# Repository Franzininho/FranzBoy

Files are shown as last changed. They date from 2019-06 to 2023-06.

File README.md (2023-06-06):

View this project on [CADLAB.io](https://cadlab.io/project/27016). 

# FranzBoy by Franzininho

FranzBoy é uma placa no formato de game. Possui display OLED, 6 teclas e é baseado no microcontolador Atmega328.

## Pinagem

OLED:
- PC4: SDA - A4
- PC5: SCL - A5
 
BOTÕES:
- UP:	PD3 - D3
- DOWN: PD4 - D4
- LEFT: PD2 - D2
- RIGHT: PD5 - D5
- A: PD6 - D6
- B: PD7 - D7

USB:
- D+: PD2 - D2
- D-: PD4 - D4

BUZZER: PB1 - D9

IR: PB2 - D10
 
LED: PB5 - D13

## upload do código usando bootloader do Arduino UNO e conversor USB/Serial

Como ainda não temos um bootloader específico para a Franzboy, vamos usar o bootloader do Arduino Uno emprestado.

Na IDE do Arduino, configure para a programação da placa Arduino UNO:
- Ferramentas-> placa: Arduino Uno

Selecione também a porta USB atribuida ao conversor USB serial.

Faça a seguinte ligação:

|  FranzBoy | Conversor USB/Serial  |
| --- | --- |
|  DTR | DTR  |
|  RX | RX  |
|  TX | TX  |
|  VCC | VCC  |
|  CTS |  CTS |
|  GND |  GND |

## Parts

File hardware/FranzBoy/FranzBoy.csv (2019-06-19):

Id | Designator | Package | Quantity | Designation | Supplier and ref
1 | U3 | TP4056_BREAKOUT | 1 | TP4056_BREAKOUT
2 | G***,G*** | invaders | 2 | LOGO
3 | REF**,REF**,REF**,REF** | MountingHole_3.2mm_M3 | 4 | MountingHole_3.2mm_M3
4 | BZ1 | Buzzer_12x9.5RM7.6 | 1 | Buzzer
5 | U1 | DIP-28_W7.62mm_Socket_LongPads | 1 | ATmega328-PU
6 | SW1,SW2,SW3,SW4,SW5,SW6 | SW_PUSH_6mm_h4.3mm | 6 | SW_Push
7 | ISP | Pin_Header_Straight_2x03_Pitch2.54mm | 1 | AVR-ISP-6
8 | R1 | R_0603_HandSoldering | 1 | 10k
9 | C1,C4 | C_0603_HandSoldering | 2 | 100nF
10 | J2 | Pin_Header_Straight_1x06_Pitch2.54mm | 1 | Conn_01x06_Male
11 | C2,C3 | C_0603_HandSoldering | 2 | 22pF
12 | Y1 | Crystal_SMD_HC49-SD_HandSoldering | 1 | 16 MHz
13 | Q1,Q2 | SOT-23_Handsoldering | 2 | MMBT3904
14 | LCD1 | Oled96 | 1 | Oled96
15 | R2,R3 | R_0603_HandSoldering | 2 | 4k7
16 | C5,C6 | C_0603_HandSoldering | 2 | 10uF
17 | D1 | LED_0603_HandSoldering | 1 | LED
18 | R4,R9,R10,R11 | R_0603_HandSoldering | 4 | 1k
19 | D2,D3 | D_MiniMELF_Handsoldering | 2 | D_Zener
20 | R5 | R_0603_HandSoldering | 1 | 1k5
21 | R6 | R_0603_HandSoldering | 1 | 1M
22 | R7,R8 | R_0603_HandSoldering | 2 | 68R
23 | D4 | D_MiniMELF_Handsoldering | 1 | 1N4148
24 | J3 | Pin_Header_Straight_1x02_Pitch2.54mm | 1 | Conn_01x02_Male
25 | U2 | SOT-223-3_TabPin2 | 1 | LM1117-3.3
26 | BT1 | CR2032_HOLDER | 1 | Battery_Cell
27 | SW7 | SW_HH_SS12D07-G4-2 | 1 | SW_SPDT
28 | REF** | MountingHole_15x3mm | 1 | MountingHole_3mm_oval
29 | D5 | LED_D5.0mm_Horizontal_O1.27mm_Z3.0mm | 1 | LD271
30 | J5 | Pin_Header_Straight_1x04_Pitch2.54mm | 1 | Conn_01x04_Male
31 | J6 | Pin_Header_Straight_1x07_Pitch2.54mm | 1 | Conn_01x07_Male
32 | JP1 | SolderJumper-2_P1.3mm_Open_TrianglePad1.0x1.5mm | 1 | SolderJumper_2_Open
33 | J4 | USB_Micro-B-LCSC-C10418-and-C40946-C319167 | 1 | USB_B_Micro
34 | G*** | logo-franzininho12_7 | 1 | LOGO
35 | G*** | bandeiraBrasil | 1 | LOGO
36 | REF*** | KiCad-Logo2_6mm_SilkScreen | 1 | KiCad-Logo2_6mm_SilkScreen
37 | G*** | invaders2 | 1 | LOGO

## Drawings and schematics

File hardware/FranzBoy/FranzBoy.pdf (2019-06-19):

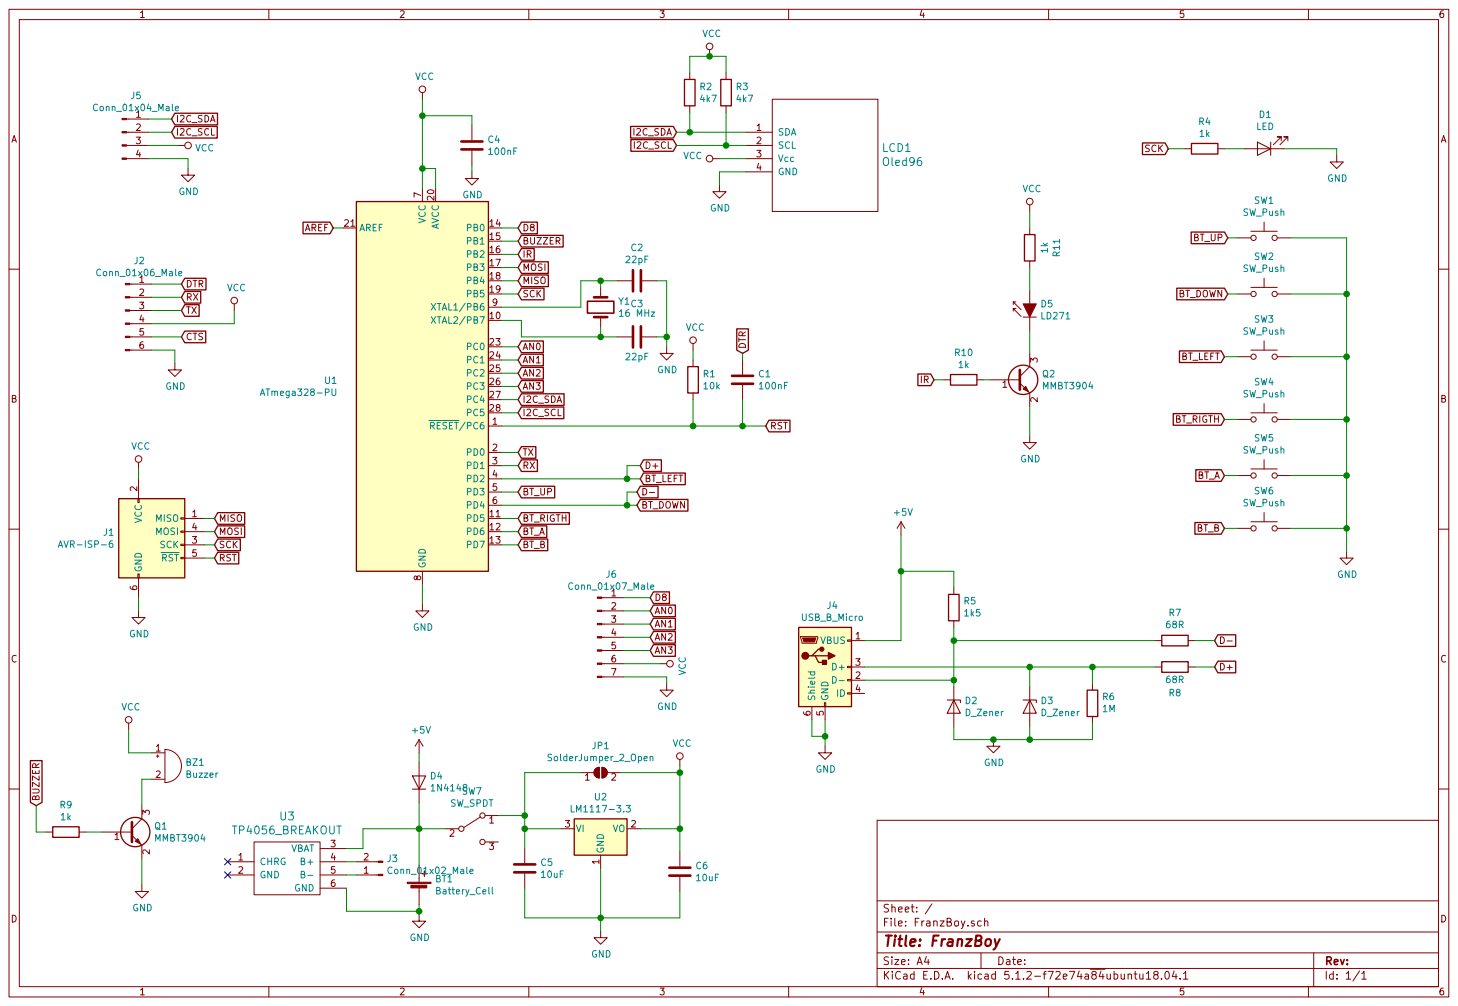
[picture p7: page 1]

2 SCK 3 MOSI 4 RST 5 GND

File: FranzBoy.sch Sheet: /
Id: 1/1 Title: FranzBoy

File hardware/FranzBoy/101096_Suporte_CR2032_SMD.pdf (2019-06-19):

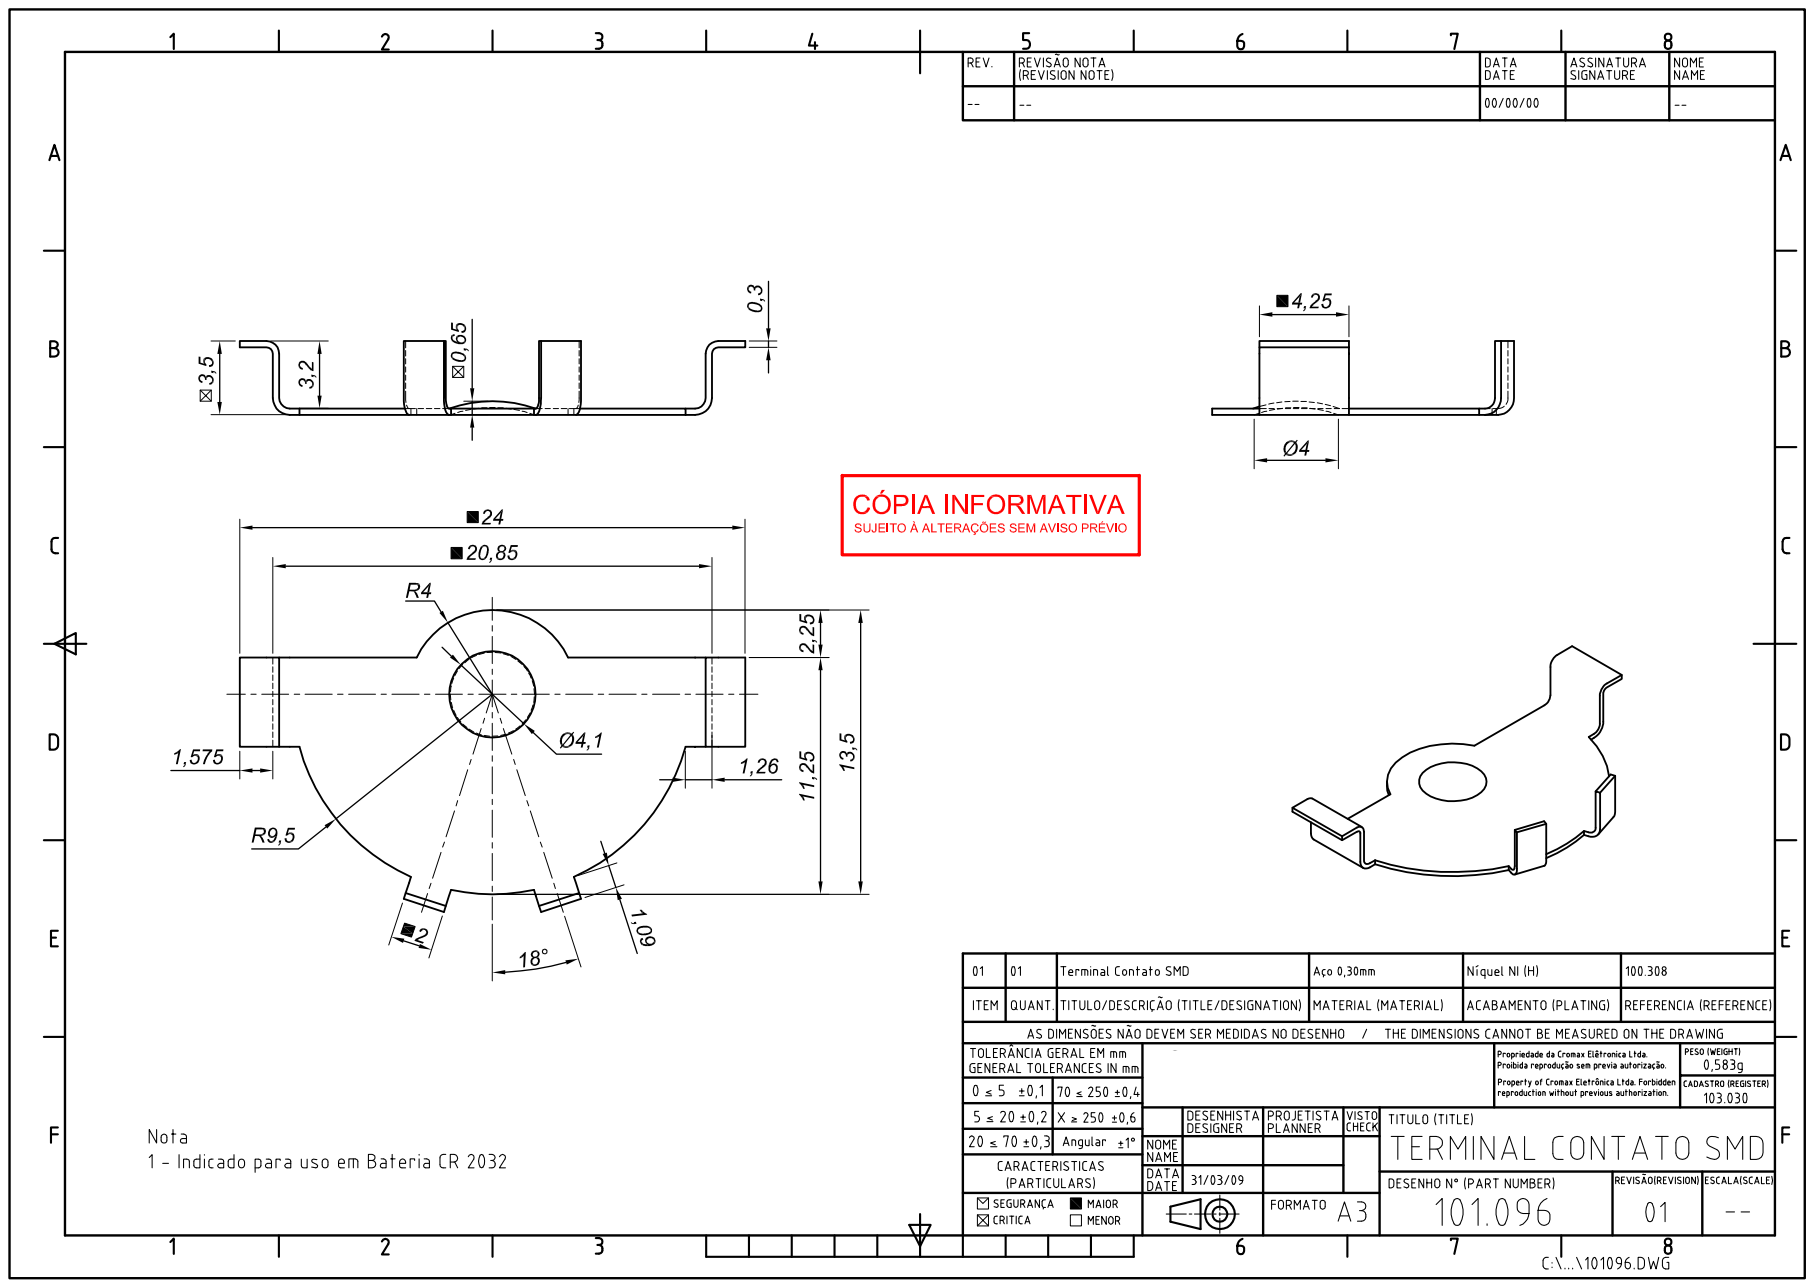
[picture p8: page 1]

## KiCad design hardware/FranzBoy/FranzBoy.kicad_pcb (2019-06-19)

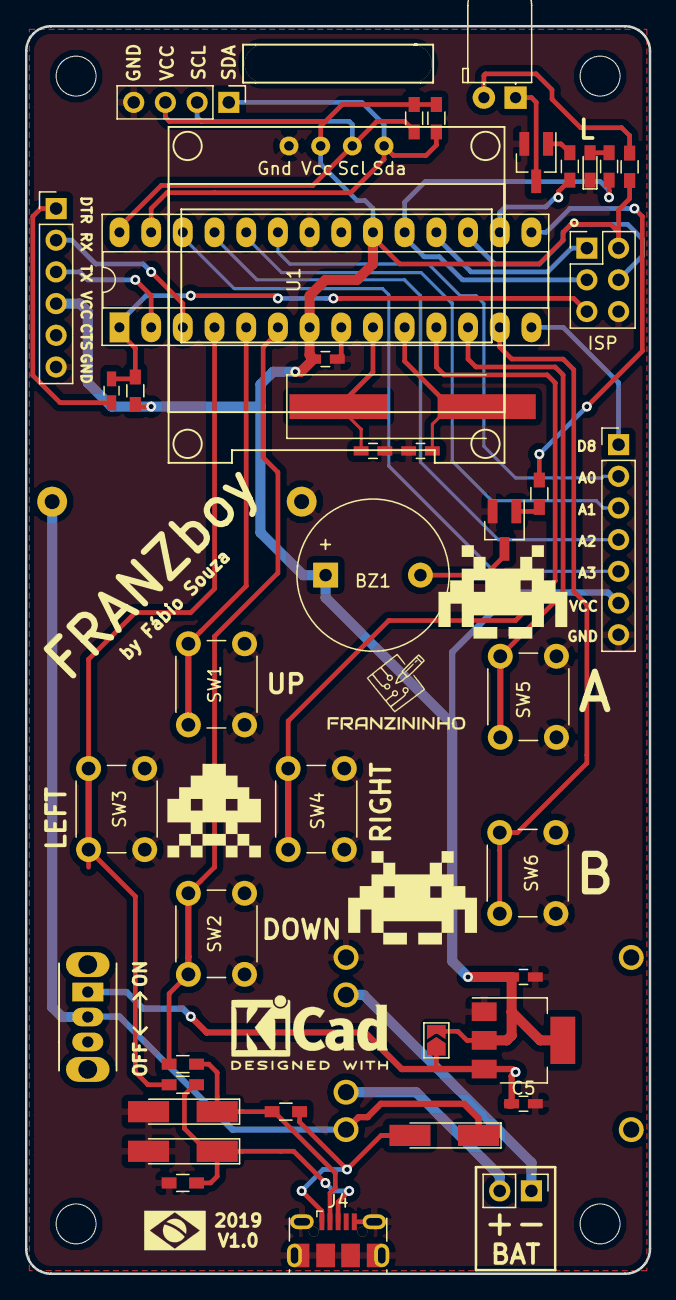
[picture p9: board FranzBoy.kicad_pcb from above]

Board: 2 copper layers, 50.0 x 100.0 mm, 45 parts (1 on the bottom side), 39 nets.

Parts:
BT1: Battery_Cell; CR2032_HOLDER
BZ1: Buzzer; Buzzer_12x9.5RM7.6
C1, C4: 100nF; C_0603_HandSoldering
C2, C3: 22pF; C_0603_HandSoldering
C5, C6: 10uF; C_0603_HandSoldering
D1: LED; LED_0603_HandSoldering
D2, D3: D_Zener; D_MiniMELF_Handsoldering
D4: 1N4148; D_MiniMELF_Handsoldering
D5: LD271; LED_D5.0mm_Horizontal_O1.27mm_Z3.0mm
ISP: AVR-ISP-6; Pin_Header_Straight_2x03_Pitch2.54mm
J2: Conn_01x06_Male; Pin_Header_Straight_1x06_Pitch2.54mm
J3: Conn_01x02_Male; Pin_Header_Straight_1x02_Pitch2.54mm
J4: USB_B_Micro; USB_Micro-B-LCSC-C10418-and-C40946-C319167
J5: Conn_01x04_Male; Pin_Header_Straight_1x04_Pitch2.54mm
J6: Conn_01x07_Male; Pin_Header_Straight_1x07_Pitch2.54mm
JP1: SolderJumper_2_Open; SolderJumper-2_P1.3mm_Open_TrianglePad1.0x1.5mm
LCD1: Oled96
Q1, Q2: MMBT3904; SOT-23_Handsoldering
R1: 10k; R_0603_HandSoldering
R2, R3: 4k7; R_0603_HandSoldering
R4, R9, R10, R11: 1k; R_0603_HandSoldering
R5: 1k5; R_0603_HandSoldering
R6: 1M; R_0603_HandSoldering
R7, R8: 68R; R_0603_HandSoldering
SW1, SW2, SW3, SW4, SW5, SW6: SW_Push; SW_PUSH_6mm_h4.3mm
SW7: SW_SPDT; SW_HH_SS12D07-G4-2
U1: ATmega328-PU; DIP-28_W7.62mm_Socket_LongPads
U2: LM1117-3.3; SOT-223-3_TabPin2
U3: TP4056_BREAKOUT
Y1: 16 MHz; Crystal_SMD_HC49-SD_HandSoldering

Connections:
+5V: D4.2, J4.1, R5.2
AN0: J6.2, U1.23
AN1: J6.3, U1.24
AN2: J6.4, U1.25
AN3: J6.5, U1.26
BT_A: SW5.1, U1.12
BT_B: SW6.1, U1.13
BT_DOWN: R7.2, SW2.1, U1.6
BT_LEFT: R8.2, SW3.1, U1.4
BT_RIGTH: SW4.1, U1.11
BT_UP: SW1.1, U1.5
BUZZER: R9.2, U1.15
D8: J6.1, U1.14
DTR: C1.1, J2.1
GND: BT1.2, C2.1, C3.1, C4.2, C5.2, C6.2, D1.1, D2.2, D3.2, ISP.6, J2.6, J4.5, J4.6, J5.4, J6.7, LCD1.4, Q1.2, Q2.2, R6.1, SW1.2, SW2.2, SW3.2, SW4.2, SW5.2, SW6.2, U1.8, U1.22, U2.1, U3.6
I2C_SCL: J5.2, LCD1.2, R3.2, U1.28
I2C_SDA: J5.1, LCD1.1, R2.2, U1.27
IR: R10.2, U1.16
MISO: ISP.1, U1.18
MOSI: ISP.4, U1.17
unnamed: BT1.1, D4.1, SW7.2, U3.3
unnamed: BZ1.2, Q1.3
unnamed: C2.2, U1.9, Y1.1
unnamed: C3.2, U1.10, Y1.2
unnamed: C5.1, JP1.1, SW7.1, U2.3
unnamed: D1.2, R4.1
unnamed: D2.1, J4.2, R5.1, R7.1
unnamed: D3.1, J4.3, R6.2, R8.1
unnamed: D5.1, Q2.3
unnamed: D5.2, R11.1
unnamed: J3.1, U3.5
unnamed: J3.2, U3.4
unnamed: Q1.1, R9.1
unnamed: Q2.1, R10.1
RST: C1.2, ISP.5, R1.2, U1.1
RX: J2.2, U1.3
SCK: ISP.3, R4.2, U1.19
TX: J2.3, U1.2
VCC: BZ1.1, C4.1, C6.1, ISP.2, J2.4, J5.3, J6.6, JP1.2, LCD1.3, R1.1, R2.1, R3.1, R11.2, U1.7, U1.20, U2.2

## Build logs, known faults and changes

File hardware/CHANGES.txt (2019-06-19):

Here we are compiling a community changelog.

If you come up with a modification of our designs, please share it with the community, log your changes below, and upload the files to our GitHub repository.

Change Format
Your name Date Description of modification

Change Log

Fabio Souza 2019-06-01 Initial release of FranzBoy under CERN OHL v1.2 or later.

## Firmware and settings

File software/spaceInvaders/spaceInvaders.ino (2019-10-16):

/***********************************************************************
 * SPACE INVADERS para FranzBoy
 * 
 * Software baseado no projeto: https://www.xtronical.com/arduino-space-invaders-making-on-stripboard/
 * e adaptado para funcionamento no FranBoy
 * 
 * Adaptação por: Fábio Souza
 * Data:01/06/19
 * 
 ***********************************************************************/

#include <Adafruit_SSD1306.h>
#include <Adafruit_GFX.h>
#include <toneAC.h>
#include <EEPROM.h>
 
// DISPLAY SETTINGS
#define OLED_ADDRESS 0x3C
#define SCREEN_WIDTH 128
#define SCREEN_HEIGHT 64
 
// Input settings
#define FIRE_BUT 6
#define RIGHT_BUT 5
#define LEFT_BUT 2


// Mothership
#define MOTHERSHIP_HEIGHT 4
#define MOTHERSHIP_WIDTH 16
#define MOTHERSHIP_SPEED 2
#define MOTHERSHIP_SPAWN_CHANCE 250         //HIGHER IS LESS CHANCE OF SPAWN
#define DISPLAY_MOTHERSHIP_BONUS_TIME 20      // how long bonus stays on screen for displaying mothership

// Alien Settings
#define ALIEN_HEIGHT 8  
#define NUM_ALIEN_COLUMNS 7
#define NUM_ALIEN_ROWS 3
#define X_START_OFFSET 6
#define SPACE_BETWEEN_ALIEN_COLUMNS 5
#define LARGEST_ALIEN_WIDTH 11
#define SPACE_BETWEEN_ROWS 9
#define INVADERS_DROP_BY 4            // pixel amount that invaders move down by
#define INVADERS_SPEED 12             // speed of movement, lower=faster.
#define INVADER_HEIGHT 8
#define EXPLOSION_GFX_TIME 7  // How long an ExplosionGfx remains on screen before dissapearing
#define INVADERS_Y_START MOTHERSHIP_HEIGHT-1
#define AMOUNT_TO_DROP_BY_PER_LEVEL 4   //NEW How much farther down aliens start per new level
#define LEVEL_TO_RESET_TO_START_HEIGHT 4  // EVERY MULTIPLE OF THIS LEVEL THE ALIEN y START POSITION WILL RESET TO TOP
#define ALIEN_X_MOVE_AMOUNT 1                       //number of pixels moved at start of wave
#define CHANCEOFBOMBDROPPING 20                     // Higher the number the rarer the bomb drop, 
#define BOMB_HEIGHT 4
#define BOMB_WIDTH 2
#define MAXBOMBS 3   // Max number of bombs allowed to drop at a time
// These two lines are for when bombs collide with the bases
#define CHANCE_OF_BOMB_DAMAGE_TO_LEFT_OR_RIGHT 3    // higher more chance
#define CHANCE_OF_BOMB_PENETRATING_DOWN 3           // higher more chance

// Player settingsc
#define TANKGFX_WIDTH 13
#define TANKGFX_HEIGHT 8
#define PLAYER_X_MOVE_AMOUNT 2
#define LIVES 3                 //NEW
#define PLAYER_EXPLOSION_TIME 10  // How long an ExplosionGfx remains on screen before dissapearing
#define PLAYER_Y_START 56
#define PLAYER_X_START 0
#define BASE_WIDTH 16               
#define BASE_WIDTH_IN_BYTES 2
#define BASE_HEIGHT 8
#define BASE_Y 46
#define NUM_BASES 3
#define BASE_MARGINS 10   

#define MISSILE_HEIGHT 4
#define MISSILE_WIDTH 1
#define MISSILE_SPEED 4

// Status of a game object constants
#define ACTIVE 0
#define EXPLODING 1
#define DESTROYED 2
 
// background dah dah dah sound setting
#define NOTELENGTH 1                      // larger means play note longer


//splash



// graphics
// aliens

 const unsigned char MotherShipGfx [] PROGMEM = {
  B00111111,B11111100,
  B01101101,B10110110,
  B11111111,B11111111,
  B00111001,B10011100
};

const unsigned char InvaderTopGfx [] PROGMEM = {
  B00011000,
  B00111100,
  B01111110,
  B11011011,
  B11111111,
  B00100100,
  B01011010,
  B10100101
};
 
const unsigned char InvaderTopGfx2 [] PROGMEM = {
  B00011000,
  B00111100,
  B01111110,
  B11011011,
  B11111111,
  B01011010,
  B10000001,
  B01000010
};
 
const unsigned char PROGMEM InvaderMiddleGfx []=
{
  B00100000,B10000000,
  B00010001,B00000000,
  B00111111,B10000000,
  B01101110,B11000000,
  B11111111,B11100000,
  B10111111,B10100000,
  B10100000,B10100000,
  B00011011,B00000000
};
 
const unsigned char PROGMEM InvaderMiddleGfx2 [] = {
  B00100000,B10000000,
  B00010001,B00000000,
  B10111111,B10100000,
  B10101110,B10100000,
  B11111111,B11100000,
  B00111111,B10000000,
  B00100000,B10000000,
  B01000000,B01000000
};
 
const unsigned char PROGMEM InvaderBottomGfx [] = {
  B00001111,B00000000,
  B01111111,B11100000,
  B11111111,B11110000,
  B11100110,B01110000,
  B11111111,B11110000,
  B00111001,B11000000,
  B01100110,B01100000,
  B00110000,B11000000
};
 
const unsigned char PROGMEM InvaderBottomGfx2 [] = {
  B00001111,B00000000,
  B01111111,B11100000,
  B11111111,B11110000,
  B11100110,B01110000,
  B11111111,B11110000,
  B00111001,B11000000,
  B01000110,B00100000,
  B10000000,B00010000
};

static const unsigned char PROGMEM ExplosionGfx [] = {
  B00001000,B10000000,
  B01000101,B00010000,
  B00100000,B00100000,
  B00010000,B01000000,
  B11000000,B00011000,
  B00010000,B01000000,
  B00100101,B00100000,
  B01001000,B10010000
};
 
// Player grafix
const unsigned char PROGMEM TankGfx [] = {
  B00000010,B00000000,
  B00000111,B00000000,
  B00000111,B00000000,
  B01111111,B11110000,
  B11111111,B11111000,
  B11111111,B11111000,
  B11111111,B11111000,
  B11111111,B11111000,
};

static const unsigned char PROGMEM MissileGfx [] = {
  B10000000,
  B10000000,
  B10000000,
  B10000000
  
};

static const unsigned char PROGMEM AlienBombGfx [] = {
  B10000000,
  B01000000,
  B10000000,
  B01000000
  
};

static const unsigned char PROGMEM BaseGfx [] = {
  B00011111,B11111000,
  B01111111,B11111110,
  B11111111,B11111111,
  B11111111,B11111111,
  B11111111,B11111111,
  B11111000,B00011111,
  B11100000,B00000111,
  B11100000,B00000111
};


static const unsigned char PROGMEM telaInicialGfx[]  =
{
0x00, 0x00, 0x00, 0x00, 0x00, 0x00, 0x00, 0x00, 0x00, 0x00, 0x00, 0x00, 0x00, 0x00, 0x00, 0x00,
0x00, 0x00, 0x00, 0x00, 0x00, 0x00, 0x00, 0x00, 0x00, 0x00, 0x00, 0x00, 0x00, 0x00, 0x00, 0x00,
0x00, 0x00, 0x00, 0x00, 0x00, 0x00, 0x03, 0x80, 0x01, 0xC0, 0x00, 0x00, 0x00, 0x00, 0x00, 0x00,
0x00, 0x00, 0x00, 0x00, 0x00, 0x00, 0x03, 0x80, 0x01, 0xC0, 0x00, 0x00, 0x00, 0x00, 0x00, 0x00,
0x00, 0x00, 0x00, 0x00, 0x00, 0x00, 0x00, 0x70, 0x0E, 0x00, 0x00, 0x00, 0x00, 0x00, 0x00, 0x00,
0x00, 0x00, 0x00, 0x00, 0x00, 0x00, 0x00, 0x70, 0x0E, 0x00, 0x00, 0x00, 0x00, 0x00, 0x00, 0x00,
0x00, 0x00, 0x00, 0x00, 0x00, 0x00, 0x00, 0x70, 0x0E, 0x00, 0x00, 0x00, 0x00, 0x00, 0x00, 0x00,
0x00, 0x00, 0x00, 0x00, 0x00, 0x00, 0x03, 0xFF, 0xFF, 0xC0, 0x00, 0x00, 0x00, 0x00, 0x00, 0x00,
0x00, 0x00, 0x00, 0x00, 0x00, 0x00, 0x03, 0xFF, 0xFF, 0xC0, 0x00, 0x00, 0x00, 0x00, 0x00, 0x00,
0x00, 0x00, 0x00, 0x00, 0x00, 0x00, 0x03, 0xFF, 0xFF, 0xC0, 0x00, 0x00, 0x00, 0x00, 0x00, 0x00,
0x00, 0x00, 0x00, 0x00, 0x00, 0x00, 0x0F, 0x8F, 0xF1, 0xF0, 0x00, 0x00, 0x00, 0x00, 0x00, 0x00,
0x00, 0x00, 0x00, 0x00, 0x00, 0x00, 0x0F, 0x8F, 0xF1, 0xF0, 0x00, 0x00, 0x00, 0x00, 0x00, 0x00,
0x00, 0x00, 0x00, 0x00, 0x00, 0x00, 0x0F, 0x8F, 0xF1, 0xF0, 0x00, 0x00, 0x00, 0x00, 0x00, 0x00,
0x00, 0x00, 0x00, 0x00, 0x00, 0x00, 0x7F, 0xFF, 0xFF, 0xFE, 0x00, 0x00, 0x00, 0x00, 0x00, 0x00,
0x00, 0x00, 0x00, 0x00, 0x00, 0x00, 0x7F, 0xFF, 0xFF, 0xFE, 0x00, 0x00, 0x00, 0x00, 0x00, 0x00,
0x00, 0x00, 0x00, 0x00, 0x00, 0x00, 0x73, 0xFF, 0xFF, 0xCE, 0x00, 0x00, 0x00, 0x00, 0x00, 0x00,
0x00, 0x00, 0x00, 0x00, 0x00, 0x00, 0x73, 0xFF, 0xFF, 0xCE, 0x00, 0x00, 0x00, 0x00, 0x00, 0x00,
0x00, 0x00, 0x00, 0x00, 0x00, 0x00, 0x73, 0xFF, 0xFF, 0xCE, 0x00, 0x00, 0x00, 0x00, 0x00, 0x00,
0x00, 0x00, 0x00, 0x00, 0x00, 0x00, 0x73, 0x80, 0x01, 0xCE, 0x00, 0x00, 0x00, 0x00, 0x00, 0x00,
0x00, 0x00, 0x00, 0x00, 0x00, 0x00, 0x73, 0x80, 0x01, 0xCE, 0x00, 0x00, 0x00, 0x00, 0x00, 0x00,
0x00, 0x00, 0x00, 0x00, 0x00, 0x00, 0x73, 0x80, 0x01, 0xCE, 0x00, 0x00, 0x00, 0x00, 0x00, 0x00,
0x00, 0x00, 0x00, 0x00, 0x00, 0x00, 0x00, 0x7E, 0x7E, 0x00, 0x00, 0x00, 0x00, 0x00, 0x00, 0x00,
0x00, 0x00, 0x00, 0x00, 0x00, 0x00, 0x00, 0x7E, 0x7E, 0x00, 0x00, 0x00, 0x00, 0x00, 0x00, 0x00,
0x00, 0x00, 0x00, 0x00, 0x00, 0x00, 0x00, 0x00, 0x00, 0x00, 0x00, 0x00, 0x00, 0x00, 0x00, 0x00,
0x00, 0x00, 0x00, 0x00, 0x00, 0x00, 0x00, 0x00, 0x00, 0x00, 0x00, 0x00, 0x00, 0x00, 0x00, 0x00,
0x00, 0x00, 0x00, 0x00, 0x00, 0x00, 0x00, 0x00, 0x00, 0x00, 0x00, 0x00, 0x00, 0x00, 0x00, 0x00,
0x00, 0x00, 0x00, 0x00, 0x00, 0x00, 0x00, 0x00, 0x00, 0x00, 0x00, 0x00, 0x00, 0x00, 0x00, 0x00,
0x00, 0x00, 0x00, 0x00, 0x00, 0x00, 0x00, 0x00, 0x00, 0x00, 0x00, 0x00, 0x00, 0x00, 0x00, 0x00,
0x00, 0x00, 0x00, 0x3F, 0xC0, 0x00, 0x00, 0x00, 0x00, 0x1F, 0x00, 0x00, 0x00, 0x00, 0x00, 0x00,
0x00, 0x00, 0x00, 0x30, 0x00, 0x00, 0x00, 0x00, 0x00, 0x31, 0x80, 0x00, 0x00, 0x00, 0x00, 0x00,
0x00, 0x00, 0x00, 0x30, 0x00, 0x00, 0x00, 0x00, 0x00, 0x30, 0xC0, 0x00, 0x00, 0x00, 0x00, 0x00,
0x00, 0x00, 0x00, 0x30, 0x00, 0x00, 0x00, 0x00, 0x00, 0x30, 0xC0, 0x00, 0x00, 0x00, 0x00, 0x00,
0x00, 0x00, 0x00, 0x30, 0x0D, 0x8F, 0x06, 0xF0, 0xFF, 0x30, 0xC1, 0xE1, 0x81, 0x80, 0x00, 0x00,
0x00, 0x00, 0x00, 0x30, 0x0F, 0x19, 0x87, 0x98, 0x03, 0x30, 0xC3, 0x30, 0xC3, 0x00, 0x00, 0x00,
0x00, 0x00, 0x00, 0x30, 0x0E, 0x00, 0xC7, 0x0C, 0x06, 0x31, 0x86, 0x18, 0xC3, 0x00, 0x00, 0x00,
0x00, 0x00, 0x00, 0x3F, 0xCC, 0x00, 0xC6, 0x0C, 0x0C, 0x3F, 0x0C, 0x0C, 0xC3, 0x00, 0x00, 0x00,
0x00, 0x00, 0x00, 0x30, 0x0C, 0x07, 0xC6, 0x0C, 0x18, 0x31, 0xCC, 0x0C, 0x66, 0x00, 0x00, 0x00,
0x00, 0x00, 0x00, 0x30, 0x0C, 0x1C, 0xC6, 0x0C, 0x18, 0x30, 0x6C, 0x0C, 0x66, 0x00, 0x00, 0x00,
0x00, 0x00, 0x00, 0x30, 0x0C, 0x30, 0xC6, 0x0C, 0x30, 0x30, 0x6C, 0x0C, 0x3C, 0x00, 0x00, 0x00,
0x00, 0x00, 0x00, 0x30, 0x0C, 0x30, 0xC6, 0x0C, 0x60, 0x30, 0x6C, 0x0C, 0x3C, 0x00, 0x00, 0x00,
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
};

// Game structures
 
struct GameObjectStruct  {
  // base object which most other objects will include
    signed int X;
    signed int Y;  
    unsigned char Status;  //0 active, 1 exploding, 2 destroyed
};
 

struct BaseStruct {
    GameObjectStruct Ord;
    unsigned char Gfx[16];
};


struct AlienStruct  {
  GameObjectStruct Ord;
  unsigned char ExplosionGfxCounter; // how long we want the ExplosionGfx to last
};
 
struct PlayerStruct  {
    GameObjectStruct Ord;
    unsigned int Score;
    unsigned char Lives;
    unsigned char Level;
    unsigned char AliensDestroyed;    // count of how many killed so far
    unsigned char AlienSpeed;         // higher the number slower they go, calculated when ever alien destroyed
    unsigned char ExplosionGfxCounter; // how long we want the ExplosionGfx to last
};


// general global variables
Adafruit_SSD1306 display(SCREEN_WIDTH, SCREEN_HEIGHT, &Wire);

 
//alien global vars
//The array of aliens across the screen
AlienStruct  Alien[NUM_ALIEN_COLUMNS][NUM_ALIEN_ROWS];
AlienStruct MotherShip;
GameObjectStruct AlienBomb[MAXBOMBS];
BaseStruct Base[NUM_BASES];

static const int TOTAL_ALIENS=NUM_ALIEN_COLUMNS*NUM_ALIEN_ROWS;  //NEW

 
// widths of aliens
// as aliens are the same type per row we do not need to store their graphic width per alien in the structure above
// that would take a byte per alien rather than just three entries here, 1 per row, saving significnt memory
byte AlienWidth[]={8,11,12};  // top, middle ,bottom widths

 
char AlienXMoveAmount=2;  
signed char InvadersMoveCounter;            // counts down, when 0 move invaders, set according to how many aliens on screen
bool AnimationFrame=false;   // two frames of animation, if true show one if false show the other

// Mothership
signed char MotherShipSpeed;
unsigned int MotherShipBonus;
signed int MotherShipBonusXPos;            // pos to display bonus at
unsigned char MotherShipBonusCounter;         // how long bonus amount left on screen


// Player global variables
PlayerStruct Player;
GameObjectStruct Missile;
 
// game variables
unsigned int HiScore;
bool GameInPlay=false;

// Sound settings and variables

// music (dah dah dah sound) control, these are the "pitch" of the four basic notes
const unsigned char Music[] =  {
  160,100,80,62
};

unsigned char MusicIndex;                     // index pointer to next note to play
unsigned MusicCounter;                        // how long note plays for countdown timer, is set to
                                              // NOTELENGTH define above

bool PlayerExplosionNoiseCompleted=false;     // flag to indicate when noise has completed
bool ShootCompleted=true;                     // stops music when this is false, so we can here shoot sound





void setup() 
{
  display.begin(SSD1306_SWITCHCAPVCC,OLED_ADDRESS);
  InitAliens(0); 
  InitPlayer();
  
  pinMode(RIGHT_BUT, INPUT_PULLUP);
  pinMode(LEFT_BUT, INPUT_PULLUP);
  pinMode(FIRE_BUT, INPUT_PULLUP);
 
  display.setTextSize(1);
  display.setTextColor(WHITE);
  
  EEPROM.get(0,HiScore);
  if(HiScore==65535)  // new unit never written to
  { 
    HiScore=0;
    EEPROM.put(0,HiScore);
  }

  display.clearDisplay();

  display.drawBitmap(0, 0,  telaInicialGfx, 128, 64,1);
  display.setCursor(27,47);
  display.print("Franzininho");
  display.setCursor(20,57);
  display.print("por Fabio Souza");
  display.display();

  delay(3000);
/*
  while(digitalRead(FIRE_BUT) == HIGH){
  delay(10);
  }*/
  
}
 
void loop()  
{  
  //NEW
  if(GameInPlay)
  {
    Physics();
    UpdateDisplay();
  }
  else  
    AttractScreen();
}

 
void AttractScreen()
{
  display.clearDisplay();   
  CentreText("Play Space Invaders",0); 
  CentreText("Press Fire to start",24); 
  CentreText("Hi Score     ",36);   
  //CentreText("Siriaco",55);   
  display.setCursor(80,36);
  display.print(HiScore);
  display.display();
  if(digitalRead(FIRE_BUT)==0){
    GameInPlay=true;
    NewGame();
  }

  // CHECK FOR HIGH SCORE RESET, PLAYER MUST HOLD LEFT AND RIGHT TOGETHER 
  if((digitalRead(LEFT_BUT)==0)&(digitalRead(RIGHT_BUT)==0))
  {
    // Reset high score, don't need to worry about debounce as will ony write to EEPROM if changed, so writes a 0 then won't write again
    // if hiscore still 0 which it will be
    HiScore=0;
    EEPROM.put(0,HiScore);
  }
}

void Physics()  {  
  if(Player.Ord.Status==ACTIVE) {
    AlienControl(); 
    MotherShipPhysics();
    PlayerControl(); 
    MissileControl();
    CheckCollisions();
  }
}

unsigned char GetScoreForAlien(int RowNumber)
{
   // returns value for killing and alien at the row indicated
   switch (RowNumber)
   {
     case 0:return 30;
     case 1:return 20;
     case 2:return 10;
   }
}

void MotherShipPhysics()  {
  if(MotherShip.Ord.Status==ACTIVE)  {// spawned, move it
    toneAC((MotherShip.Ord.X % 8)*500,7,200,true);
    MotherShip.Ord.X+=MotherShipSpeed;
    if(MotherShipSpeed>0)   // going left to right , check if off right hand side
    {
      if(MotherShip.Ord.X>=SCREEN_WIDTH)  
      {
        MotherShip.Ord.Status=DESTROYED;
        noToneAC();
      }
    }
    else    // going right to left , check if off left hand side
    {
      if(MotherShip.Ord.X+MOTHERSHIP_WIDTH<0)  
      {
        MotherShip.Ord.Status=DESTROYED;
        noToneAC();
      }
    }
    
  }
  else  {
    // try to spawn mothership
    if(random(MOTHERSHIP_SPAWN_CHANCE)==1)
    {
      // Spawn a mother ship, starts just off screen at top
      MotherShip.Ord.Status=ACTIVE;
      // need to set direction
      if(random(2)==1) // values between 0 and 1
      {
        MotherShip.Ord.X=SCREEN_WIDTH;
        MotherShipSpeed=-MOTHERSHIP_SPEED;         // if we go in here swaps to right to left 
      }
      else
      {
        MotherShip.Ord.X=-MOTHERSHIP_WIDTH;
        MotherShipSpeed=MOTHERSHIP_SPEED;  // set to go left ot right      
      }
    }
  }
}
 
void PlayerControl()  {
  // user input checks
  if((digitalRead(RIGHT_BUT)==0)&(Player.Ord.X+TANKGFX_WIDTH<SCREEN_WIDTH))
    Player.Ord.X+=PLAYER_X_MOVE_AMOUNT;
  if((digitalRead(LEFT_BUT)==0)&(Player.Ord.X>0))
    Player.Ord.X-=PLAYER_X_MOVE_AMOUNT;
  if((digitalRead(FIRE_BUT)==0)&(Missile.Status!=ACTIVE))  
  {
    Missile.X=Player.Ord.X+(TANKGFX_WIDTH/2);
    Missile.Y=PLAYER_Y_START;
    Missile.Status=ACTIVE;
    noiseAC(200,10,&ShootCompleted);
  }
}

void MissileControl()
{ 
  if(Missile.Status==ACTIVE)  
  {
    Missile.Y-=MISSILE_SPEED;
    if(Missile.Y+MISSILE_HEIGHT<0)       // If off top of screen destroy so can be used again
      Missile.Status=DESTROYED;
  }
}


void AlienControl()
{
  if((InvadersMoveCounter--)<0)
  {
    bool Dropped=false;
    if((RightMostPos()+AlienXMoveAmount>=SCREEN_WIDTH) |(LeftMostPos()+AlienXMoveAmount<0)) // at edge of screen
    {
      AlienXMoveAmount=-AlienXMoveAmount;               // reverse direction
      Dropped=true;                                     // and indicate we are dropping
    }

    // play background music note if other higher priority sounds not playing
    if((ShootCompleted)&(MotherShip.Ord.Status!=ACTIVE))  {
      toneAC(Music[MusicIndex],2,100,true);
      MusicIndex++;
      if(MusicIndex==sizeof(Music))
        MusicIndex=0;
      MusicCounter=NOTELENGTH;
    }
    // update the alien postions
    for(int Across=0;Across<NUM_ALIEN_COLUMNS;Across++) 
    {
      for(int Down=0;Down<3;Down++)
      {
        if(Alien[Across][Down].Ord.Status==ACTIVE)
        {
          if(Dropped==false)
            Alien[Across][Down].Ord.X+=AlienXMoveAmount;
          else
            Alien[Across][Down].Ord.Y+=INVADERS_DROP_BY;
        }
      }
    }  
    InvadersMoveCounter=Player.AlienSpeed;
    AnimationFrame=!AnimationFrame;  ///swap to other frame
  }
  // should the alien drop a bomb
  if(random(CHANCEOFBOMBDROPPING)==1)  
    DropBomb();
  MoveBombs();
}
 
 
void MoveBombs(){
  for(int i=0;i<MAXBOMBS;i++){
    if(AlienBomb[i].Status==ACTIVE)
      AlienBomb[i].Y+=2;
  }
}


void DropBomb()  {
  // if there is a free bomb slot then drop a bomb else nothing happens
  bool Free=false;
  unsigned char ActiveCols[NUM_ALIEN_COLUMNS];  
  unsigned char BombIdx=0;
  // find a free bomb slot
  while((Free==false)&(BombIdx<MAXBOMBS)){
    if(AlienBomb[BombIdx].Status==DESTROYED)
      Free=true;
    else
      BombIdx++;
  }
  if(Free)  {
    unsigned char Columns=0;
    // now pick and alien at random to drop the bomb
    // we first pick a column, obviously some columns may not exist, so we count number of remaining cols 
    // first, this adds time but then also picking columns randomly that don't exist may take time also
    unsigned char ActiveColCount=0;
    signed char Row;
    unsigned char ChosenColumn;
    
    while(Columns<NUM_ALIEN_COLUMNS){
      Row=2;
      while(Row>=0)  {
        if(Alien[Columns][Row].Ord.Status==ACTIVE)
        {
          ActiveCols[ActiveColCount]=Columns;
          ActiveColCount++;
          break;
        }
        Row--;
      }
      Columns++;
    }
    // we have ActiveCols array filled with the column numbers of the active cols and we have how many
    // in ActiveColCount, now choose a column at random
    ChosenColumn=random(ActiveColCount);  // random number between 0 and the amount of columns
    // we now find the first available alien in this column to drop the bomb from
    Row=2;
    while(Row>=0)  {
      if(Alien[ActiveCols[ChosenColumn]][Row].Ord.Status==ACTIVE)  {
        // Set the bomb from this alien
        AlienBomb[BombIdx].Status=ACTIVE;
        AlienBomb[BombIdx].X=Alien[ActiveCols[ChosenColumn]][Row].Ord.X+int(AlienWidth[Row]/2);
        // above sets bomb to drop around invaders centre, here we add a litrle randomness around this pos
        AlienBomb[BombIdx].X=(AlienBomb[BombIdx].X-2)+random(0,4);
        AlienBomb[BombIdx].Y=Alien[ActiveCols[ChosenColumn]][Row].Ord.Y+4;        
        break;
      }
      Row--;
    }
  }
}



void BombCollisions()
{
  //check bombs collisions
  for(int i=0;i<MAXBOMBS;i++)
  {
    if(AlienBomb[i].Status==ACTIVE)
    {
      if(AlienBomb[i].Y>64)             // gone off bottom of screen
        AlienBomb[i].Status=DESTROYED;
      else  
      {
        // HAS IT HIT PLAYERS missile
          if(Collision(AlienBomb[i],BOMB_WIDTH,BOMB_HEIGHT,Missile,MISSILE_WIDTH,MISSILE_HEIGHT))
          {
              // destroy missile and bomb
              AlienBomb[i].Status=EXPLODING;
              Missile.Status=DESTROYED;
          }
          else
          {      
             // has it hit players ship          
            if(Collision(AlienBomb[i],BOMB_WIDTH,BOMB_HEIGHT,Player.Ord,TANKGFX_WIDTH,TANKGFX_HEIGHT))
            {
               PlayerHit();
               AlienBomb[i].Status=DESTROYED;
            }
            else  
              BombAndBasesCollision(&AlienBomb[i]);
          }
       }
    }
  }  
}
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

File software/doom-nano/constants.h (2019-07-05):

#ifndef _constants_h
#define _constants_h

// Key pinout
#define USE_INPUT_PULLUPS
#define K_LEFT              2
#define K_RIGHT             5
#define K_UP                3
#define K_DOWN              4
#define K_FIRE              6

// GFX settings
#define OPTIMIZE_SSD1306                // Optimizations for SSD1366 displays

#define FRAME_TIME          66.666666   // Desired time per frame in ms (66.666666 is ~15 fps)
#define RES_DIVIDER         2           // Hgher values will result in lower horizontal resolution when rasterize and lower process and memory usage
                                        // Lower will require more process and memory, but looks nicer
#define Z_RES_DIVIDER       2           // Zbuffer resolution divider. We sacrifice resolution to save memory
#define DISTANCE_MULTIPLIER 20          // Distances are stored as uint8_t, mutiplying the distance we can obtain more precision taking care
                                        // of keep numbers inside the type range. Max is 256 / MAX_RENDER_DEPTH
#define MAX_RENDER_DEPTH    12
#define MAX_SPRITE_DEPTH    8

#define ZBUFFER_SIZE        SCREEN_WIDTH / Z_RES_DIVIDER

// Level 
#define LEVEL_WIDTH         64
#define LEVEL_HEIGHT        57
#define LEVEL_SIZE          LEVEL_WIDTH / 2 * LEVEL_HEIGHT

// scenes
#define INTRO                 0
#define GAME_PLAY             1

// Game
#define GUN_TARGET_POS        18
#define GUN_SHOT_POS          GUN_TARGET_POS + 4

#define ROT_SPEED             .12
#define MOV_SPEED             .2
#define MOV_SPEED_INV         5           // 1 / MOV_SPEED

#define JOGGING_SPEED         .005
#define ENEMY_SPEED           .02
#define FIREBALL_SPEED        .2
#define FIREBALL_ANGLES       45          // Num of angles per PI

#define MAX_ENTITIES          10          // Max num of active entities
#define MAX_STATIC_ENTITIES   28          // Max num of entities in sleep mode

#define MAX_ENTITY_DISTANCE   200         // * DISTANCE_MULTIPLIER
#define MAX_ENEMY_VIEW        80          // * DISTANCE_MULTIPLIER
#define ITEM_COLLIDER_DIST    6           // * DISTANCE_MULTIPLIER
#define ENEMY_COLLIDER_DIST   4           // * DISTANCE_MULTIPLIER
#define FIREBALL_COLLIDER_DIST 2          // * DISTANCE_MULTIPLIER
#define ENEMY_MELEE_DIST      6           // * DISTANCE_MULTIPLIER
#define WALL_COLLIDER_DIST    .2

#define ENEMY_MELEE_DAMAGE    8
#define ENEMY_FIREBALL_DAMAGE 20
#define GUN_MAX_DAMAGE        15

#endif

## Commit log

2019-06-19 Adionado projeto de hardware
    [FranzBoy-B.Cu.gbl, FranzBoy-B.Mask.gbs, FranzBoy-B.Paste.gbp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]
2019-06-19 pdf do schematico
2019-10-16 Ajuste de construção do display OLED
2019-10-18 Adiconado visualizalção para montagem através da ferramenta Interactive HTML BOM
